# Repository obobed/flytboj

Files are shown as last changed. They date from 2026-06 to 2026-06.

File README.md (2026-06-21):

# flytboj - a mod for the IKEA Pelarboj.

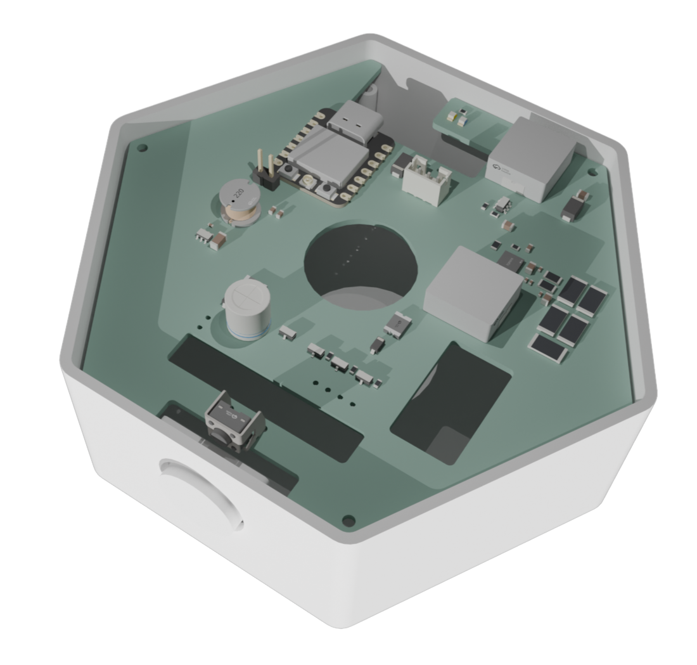
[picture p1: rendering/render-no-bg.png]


## Intro and Purpose
The Ikea Pelarboj is a cool but very basic table lamp, with a single button and a tiny PCB that switches between 3 presets. I've owned a Pelarboj
for a while now and have always wanted a mod for it, to make it more capable and powerful, preferably using software like WLED and eventually smarthome integration, hence the reason 
why I created this, the Flytboj (swedish for flat buoy, scroll down for more etymology :D), a board using the XIAO ESP32-3C, allowing me much finer control over the lamp in a smart
form factor that can securely fit into the existing case without any need for modifications or the destruction of it.

(in the real assembled version, the components should be facing down to allow space for the actual original LED board, but here it's the wrong side up in order to showcase the PCB so you can see more than just a blank back plane of the pcb.


## Name
Pelarboj is a compound word in Swedish composed of pelare (pillar) and buoy (boj). I wanted to find a name similar to this style, and originally (or maybe not so much) thought of plattboj, flat and buoy, referncing how this mod just gets squeezed in between that LEDs and big void.
However, that name is already taken (shocker, no original thoughts exist these days 😭) in the form of disposable cell batteries, forcing me to settle on the alternative, flytboj: floating buoy ("floating" in between that layers of the interior).

## OnShape
[https://cad.onshape.com/documents/6a6cc990155203ee9358141d/w/edd2b1eb29a5a3bfc9bf4f54/e/d732d6e58b55189afc99dc7b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](https://cad.onshape.com/documents/6a6cc990155203ee9358141d/w/edd2b1eb29a5a3bfc9bf4f54/e/d732d6e58b55189afc99dc7b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)

## PCB
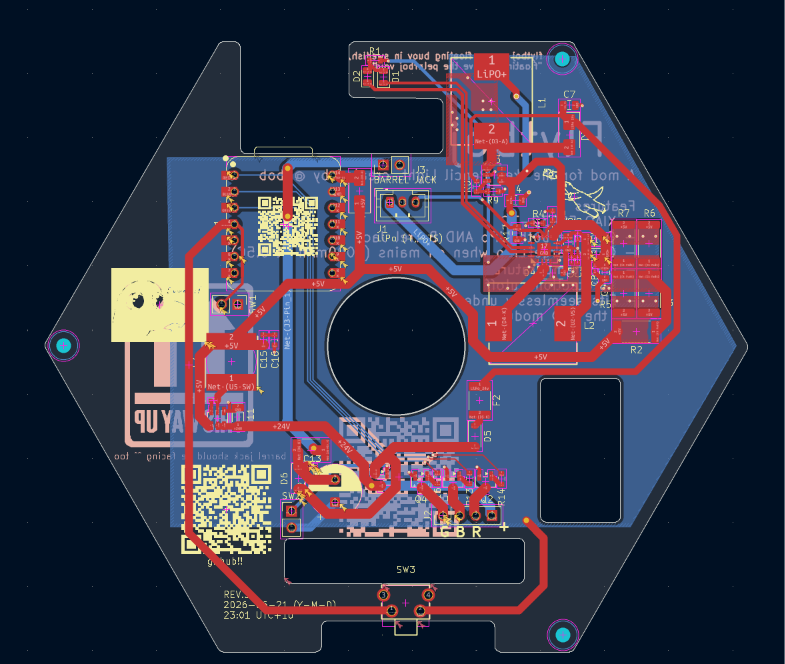
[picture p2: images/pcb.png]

## Schematic

## 3D

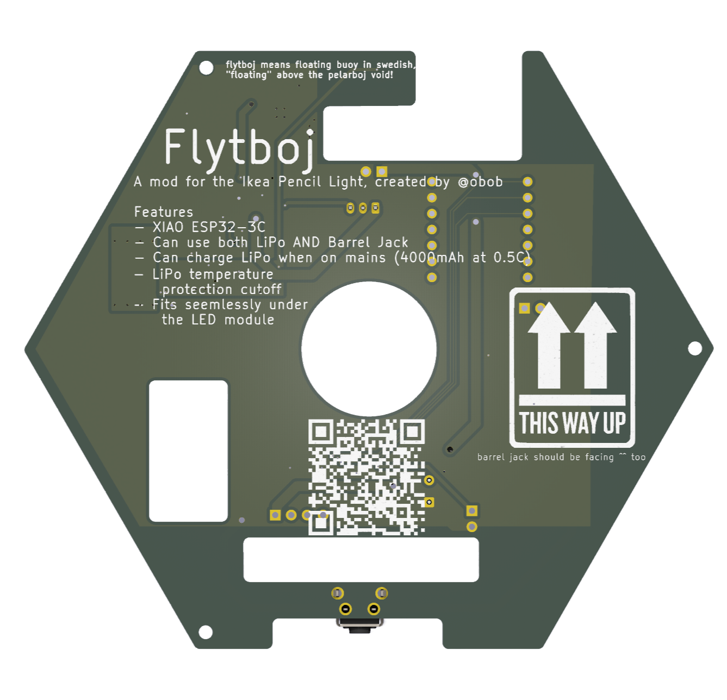
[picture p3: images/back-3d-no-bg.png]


## Assembly
BEFOREHAND:
Flash and setup [WLED](https://kno.wled.ge/) on your controller.
This has a pretty straightforward assembly:
1. use a phillips head screwdriver to undo the big large screw at the back of the PELARBOJ (right on top of where the barrel plug goes)
2. twist and pull the top enclosure up and off
3. undo the 3 smaller screws and take off the LED module
4. remove the existing PCB, first by taking the bracket out and then removing the pcb from the bracket
5. use a soldering iron to unsolder the pos and neg barrel jack wires (left on this image)
   og-pcb
6. do the same with the leds wires on the right. keep track of the order they are originally in.
IF USING A LiPo:
7. place foam strips down to position the battery
8. place the battery downon the strips
9. put Flytboj into the correct place above the enclosure and plug the battery in.

Otherwise:

10. Place Flytboj **upside down** onto the poles
11. Route the barrel jack traces through the cuts in the board into a good position to solder
12. Solder the barrel jack cables and the LED cables (routed through the big circle in the middle)
13. Put the LED module back on
14. Screw everything up
15. Plug in and enjoy

## BOM
### Overall
|Item |Cost (USD)|Notes |Link |
|---|---|---|---|
|PCB |$8.50 | |https://jlcpcb.com/ |
|PCB Shipping |8.17 | |https://jlcpcb.com/ |
|PCBA |50.74 |-$8 with PCBA coupon|https://jlcpcb.com/ |
|XIAO ESP32-3C|9.46 | |https://www.aliexpress.com/item/1005008791937363.html|
|antenna |0.35 |buy with the XIAO |https://www.aliexpress.com/item/1005008791937363.html|
|lipo battery |7.7 |4000mAh |https://www.aliexpress.com/item/1005009212214659.html|
| | | | |
|Total |$84.92 | | |

### PCBA Component BOM (included under PCBA in overall BOM)
|Designator |Footprint|Quantity |Value |LCSC Part #|DNP|Cost |Notes |
|---|---|---|---|---|---|---|---|
|C1 |0402 |1 |10u |C15525 | |0.0394 | |
|C11 |1206 |1 |10u |C13585 | |0.2836 | |
|C12 |CP_Radial_D8.0mm_P3.50mm|1 |100u |C2749 | |0.1254 |extended |
|C13, C3, C4, C5, C8|0402 |4 |100n |C307331 | |0.0760 | |
|C15, C16 |0603 |2 |22u |C59461 | |0.0944 | |
|C2 |0603 |1 |100n |C14663 | |0.0236 | |
|C4, C7 |0805 |2 |22u |C45783 | |0.4696 | |
|C6, C9 |0805 |2 |10u |C440198 | |0.8424 | |
|D1 |0805 |1 |GREEN |C2297 | |0.0324 | |
|D2 |0805 |1 |RED |C84256 | |0.0266 | |
|D4, D5, D6 |D_SOD-123|2 |D_Schottky |C8598 | |0.1548 | |
|D3, D7 |D_SMA |1 |D_Schottky |C22452 | |0.1452 | |
|F1, F2 |1812 |2 |5A |C20617446  | |0.6066 |jlcpcb has no basic fuses |
|J1 |JST_PH_B3B-PH-K_1x03_P2.00mm_Vertical|1 |Conn_01x03_Pin |C131339 | |0.1233 |same here, no basic PH connectors |
|J2 |PinHeader_1x04_P2.54mm_Vertical|1 |Conn_01x04 | |X  | | |
|J3 |PinHeader_1x02_P2.54mm_Vertical|1 |Conn_02x01 | |X  | | |
|L1, L2 |IND-SMD_L13.5-W12.5|2 |10u |C840531 | |4.1444 |again, no basic 10uH inductors of any size|
|L3 |IND-SMD_L7.8-W7.8_SDR0805|1 |4.7u |C1329416 | |0.9314 |and here |
|Q1, Q2, Q4 |SOT-23 |3 |AO3400A |C20917 | |0.5028 | |
|Q3 |SOT-23 |1 |AO3401A |C15127 | |0.1418 | |
|R1 |0603 |1 |1k |C21190 | |0.0320 | |
|R10, R11 |1206 |2 |100m |C25334 | |0.0256 | |
|R12 |0805 |1 |10k |C17414 | |0.0068 | |
|R13, R14, R15|0603 |3 |100 |C22775 | |0.0138 | |
|R2, R3, R5, R6, R7|2512 |5 |1 |C5127857 | |2.8530 |extended - need to handle 2W of current |
|R4 |0603 |1 |49.9k |C23184 | |0.0036 | |
|R8 |0603 |1 |100k |C25803 | |0.0032 | |
|R9 |0603 |1 |390k |C23150 | |0.0380 |promotional extended part - no $5 fee |
|SW1 |PinHeader_1x02_P2.54mm_Vertical|1 |SW_Push | |X  | | |
|SW2 |PinHeader_1x02_P2.54mm_Vertical|1 |SW_SPST | |X  | | |
|SW3 |SW-TH_TS665ZJ|1 |SW_Push |C557599 | |0.1032 |extended |
|U2 |TQFN-16_L4.0-W4.0-P0.65-BL-EP|1 |TP5100_C379389 |C379389 | |1.0926 |extended |
|U3 |SOT-23-6 |1 |MT3608 |C84817 | |0.399  |extended |
|U5 |TSOT-23-6|1 |AP63205WU |C2071056 | |0.8734 |extended |
| | | | | | | | |
|Total | | | | | |14.2079| |

## zine!!
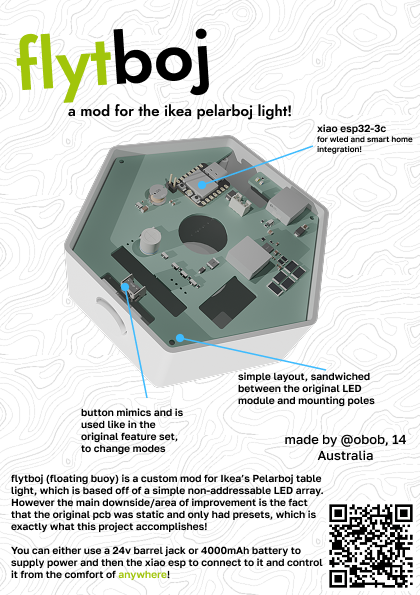
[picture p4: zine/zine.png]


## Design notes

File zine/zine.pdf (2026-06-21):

## flytboj a mod for the ikea pelarboj light!

xiao esp32-3c

for wled and smart home

integration!

button mimics and is

used like in the

original feature set,

to change modes

flytboj (floating buoy) is a custom mod for Ikea’s Pelarboj table

light, which is based off of a simple non-addressable LED array.

However the main downside/area of improvement is the fact

that the original pcb was static and only had presets, which is

exactly what this project accomplishes!

You can either use a 24v barrel jack or 4000mAh battery to

supply power and then the xiao esp to connect to it and control

it from the comfort of anywhere!

simple layout, sandwiched

between the original LED

module and mounting poles

## made by @obob, 14

## Australia

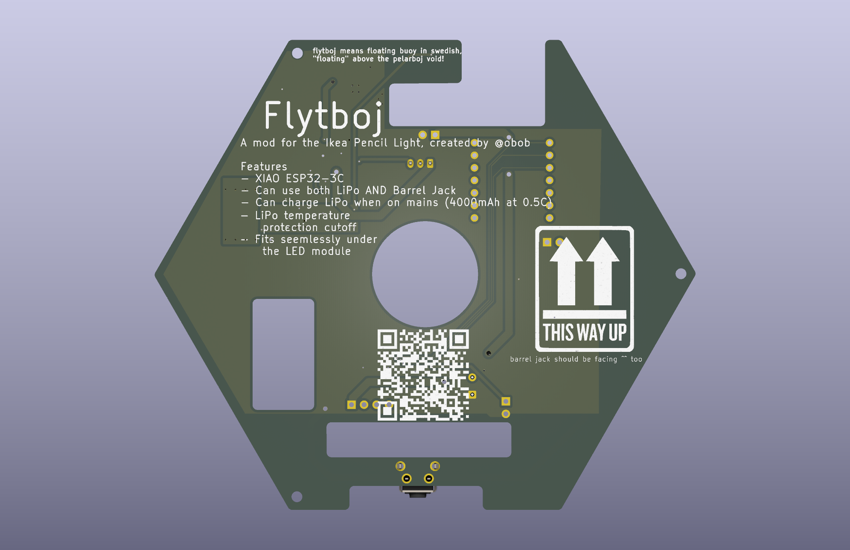
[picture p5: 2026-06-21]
images/back-3d.png

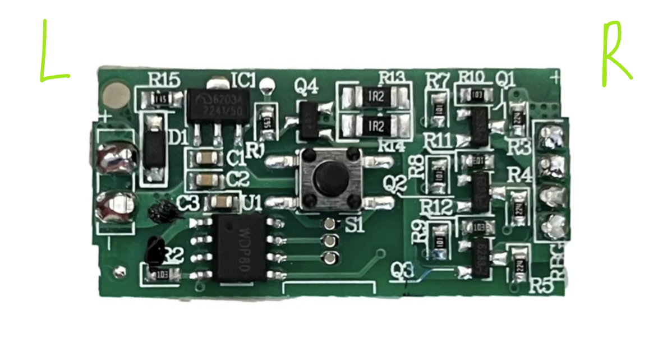
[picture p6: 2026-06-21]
images/og-pcb.png

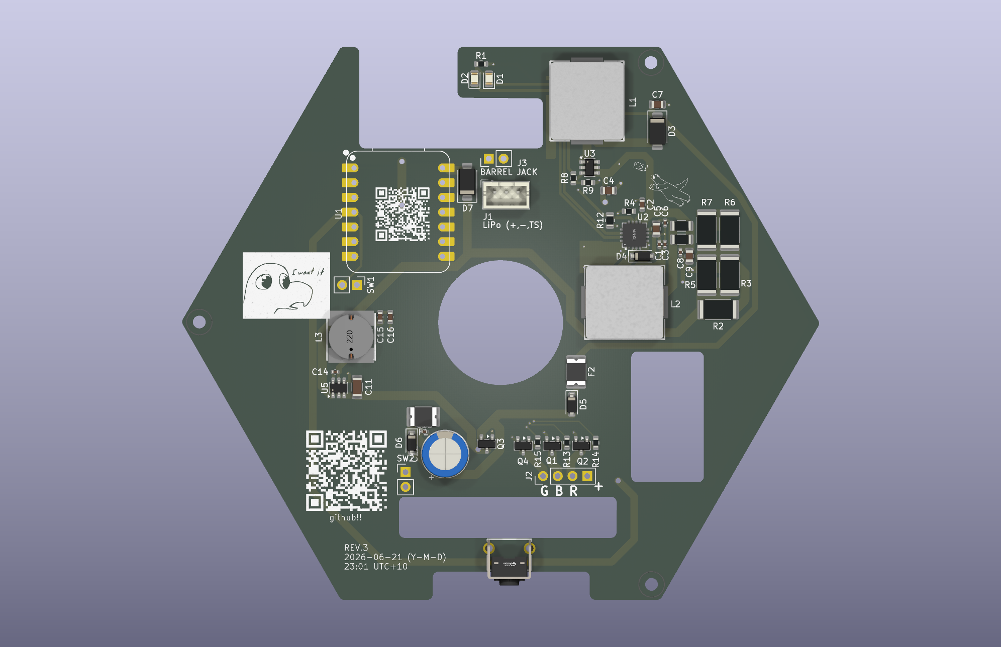
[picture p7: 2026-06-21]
images/front-3d.png

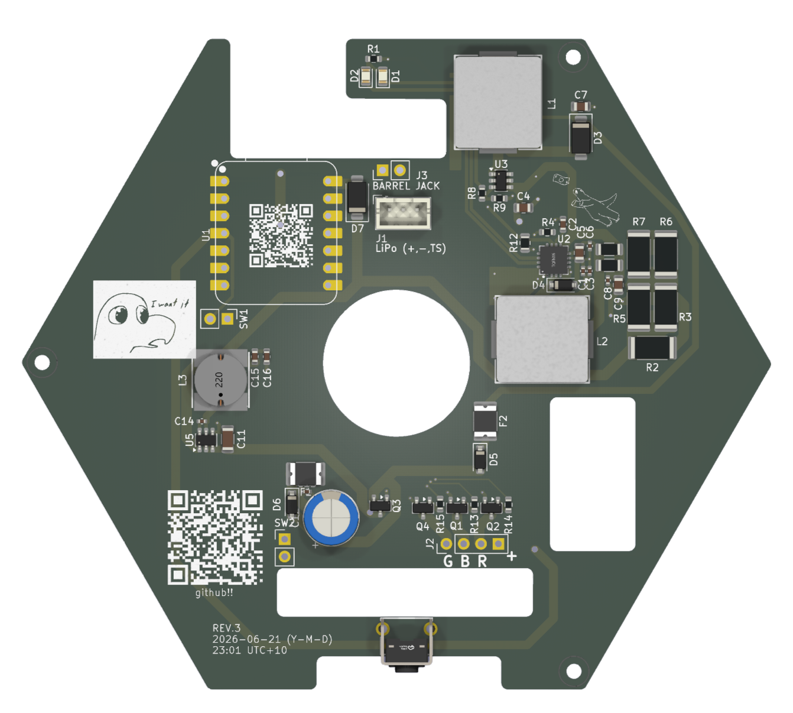
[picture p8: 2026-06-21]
images/front-3d-no-bg-.png

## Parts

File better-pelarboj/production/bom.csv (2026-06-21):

Designator | Footprint | Quantity | Value | LCSC Part #
C1 | 0402 | 1 | 10u | C15525
C11 | 1206 | 1 | 10u | C13585
C12 | CP_Radial_D8.0mm_P3.50mm | 1 | 100u | C2749
C13, C14, C3, C5, C8 | 0402 | 5 | 100n | C307331
C15, C16 | 0603 | 2 | 22u | C59461
C2 | 0603 | 1 | 100n | C14663
C4, C7 | 0805 | 2 | 22u | C45783
C6, C9 | 0805 | 2 | 10u | C440198
D1 | 0805 | 1 | GREEN | C2297
D2 | 0805 | 1 | RED | C84256
D3, D7 | D_SMA | 2 | D_Schottky | C22452
D4, D5, D6 | D_SOD-123 | 3 | D_Schottky | C8598
F1, F2 | 1812 | 2 | 5A | C20617446
J1 | JST_PH_B3B-PH-K_1x03_P2.00mm_Vertical | 1 | Conn_01x03_Pin | C131339
L1, L2 | IND-SMD_L13.5-W12.5 | 2 | 10u | C840531
L3 | IND-SMD_L7.8-W7.8_SDR0805 | 1 | 4.7u | C1329416
Q1, Q2, Q4 | SOT-23 | 3 | AO3400A | C20917
Q3 | SOT-23 | 1 | AO3401A | C15127
R1 | 0603 | 1 | 1k | C21190
R10, R11 | 1206 | 2 | 100m | C25334
R12 | 0805 | 1 | 10k | C17414
R13, R14, R15 | 0603 | 3 | 100 | C22775
R2, R3, R5, R6, R7 | 2512 | 5 | 1 | C5127857
R4 | 0603 | 1 | 49.9k | C23184
R8 | 0603 | 1 | 100k | C25803
R9 | 0603 | 1 | 390k | C23150
SW1 | PinHeader_1x02_P2.54mm_Vertical | 1 | SW_Push | C720477
SW2 | PinHeader_1x02_P2.54mm_Vertical | 1 | SW_SPST
SW3 | SW-TH_TS665ZJ | 1 | SW_Push | C557599
U1 | XIAO-ESP32-C3-DIP | 1 | XIAO-ESP32-C3-DIP
U2 | TQFN-16_L4.0-W4.0-P0.65-BL-EP | 1 | TP5100_C379389 | C379389
U3 | SOT-23-6 | 1 | MT3608 | C84817
U5 | TSOT-23-6 | 1 | AP63205WU | C2071056

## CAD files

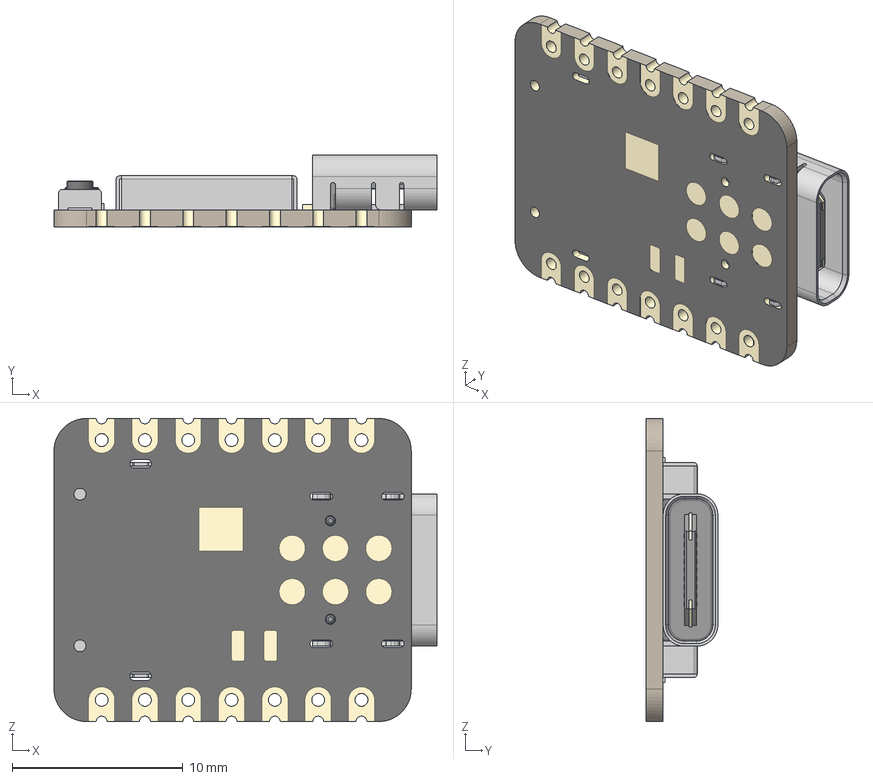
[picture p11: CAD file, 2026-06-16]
better-pelarboj/3D/seeed-studio-xiao-esp32-c3-1.snapshot.8/Seeed Studio XIAO-ESP32-C3.step
22.5 x 4.21 x 17.8 mm
BOSS-EXTRUDE14_8_
BOSS-EXTRUDE7_4_
BOSS-EXTRUDE7_3_
BOSS-EXTRUDE14_4_
BOSS-EXTRUDE14_2_
BOSS-EXTRUDE14_11_
BOSS-EXTRUDE7_7_
BOSS-EXTRUDE14_9_
BOSS-EXTRUDE14_3_
BOSS-EXTRUDE14_7_
MIRROR2
BOSS-EXTRUDE14_5_
BOSS-EXTRUDE14_12_
BOSS-EXTRUDE7_8_
BOSS-EXTRUDE7_1_
BOSS-EXTRUDE14_10_
BOSS-EXTRUDE7_9_
BOSS-EXTRUDE14_6_
BOSS-EXTRUDE14_1_
BOSS-EXTRUDE7_6_
BOSS-EXTRUDE7_2_
CUT-EXTRUDE5
BOSS-EXTRUDE7_5_
U.FL Connector v1
Button (1) x 2
Shield

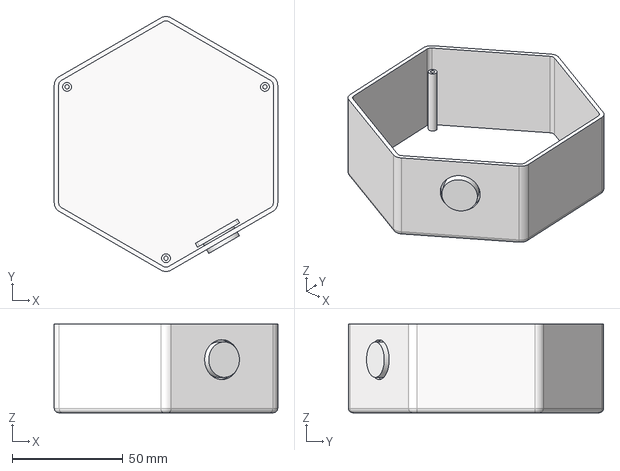
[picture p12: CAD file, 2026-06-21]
cad/original-box.step
101.0 x 115.2 x 40.0 mm

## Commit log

2026-06-15 schema + pcb parrts placement
    [better-pelarboj.kicad_pcb, better-pelarboj.kicad_sch]
2026-06-16 pcb done agaiin (fixed lots of drc and designators. ooh, also a cool 90 deg button
    [Seeed Studio XIAO-ESP32-C3.step, better-pelarboj.kicad_pcb, better-pelarboj.kicad_sch]
2026-06-21 imgs and final touches
    [OVERALL.csv, PCBA_BOM.csv, better-pelarboj.kicad_pcb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]
